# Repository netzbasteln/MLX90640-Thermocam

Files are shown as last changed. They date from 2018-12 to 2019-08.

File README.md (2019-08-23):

# MLX90640-Thermocam

We built a simple Thermal camera using the MLX90640 Sensor, an ESP32, a ILI9341 TFT, a 18650 battery in a 3D printed case.
It was featured in Netzbasteln #111: http://www.netzbasteln.de/#111 and still lacks interpolation.

Code Based on:
- Thermal Camera with image saving capability https://github.com/wilhelmzeuschner/arduino_thermal_camera_with_sd_and_img_processing
- SparkFun MLX90640 Examples https://github.com/sparkfun/SparkFun_MLX90640_Arduino_Example
- TFT_eSPI Library: https://github.com/Bodmer/, important: copy the included TFT_eSPI/Setup_User.h into the librar folder.

Hardware:
- ESP32 Devkit 4 (or any other ESP32): https://www.espressif.com/en/products/hardware/esp32-devkitc/overview
- MLX90640 Sensor Breakout Board: https://shop.pimoroni.com/products/mlx90640-thermal-camera-breakout (or the Sparkfun one)
- Display ILI9341 2.8": https://www.amazon.de/gp/product/B07DPMV34R/, https://www.pjrc.com/store/display_ili9341.html
- Charger TP4056: https://www.watterott.com/de/TP4056-Micro-USB-5V-1A-Lithium-Battery-Charger-with-Protection
- Battery 18650
- 3D Printed case:

ESP32 Pins (GND/VCC is obvious ;)
```
SENSOR_SDA 21
SENSOR_SCL 22
TFT_MISO 19
TFT_MOSI 23
TFT_SCLK 18
TFT_CS   15
TFT_DC    2
TFT_RST   4
```

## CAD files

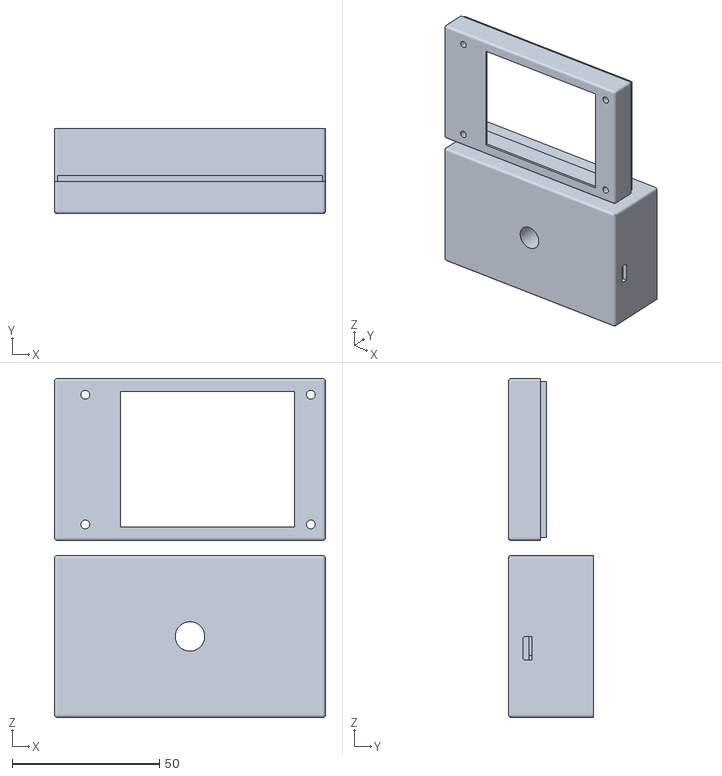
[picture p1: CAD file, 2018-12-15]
Wärmebildkamera-Gehäuse v49.stl
92.0 x 29.0 x 115.0

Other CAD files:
Wärmebildkamera-Gehäuse-v49.f3d

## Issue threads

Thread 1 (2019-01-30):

Which button to use?

weases, 2019-01-30:
I do not see a button to turn on/off the camera in the hardware list but it seems like there is a cut-out in the case. Can you point me in the direction which button was used in the project/would fit?

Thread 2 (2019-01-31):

'class TwoWire' has no member named 'transact'

digitalflower, 2019-01-31:
first of all thanks for the great project & podcast!

I installed the ESP32 core fork as described here: https://github.com/stickbreaker/arduino-esp32/blob/master/docs/arduino-ide/mac.md

But when compiling I get the following error:

```
sketch/MLX90640_I2C_Driver.cpp: In function 'int MLX90640_I2CRead(uint8_t, unsigned int, unsigned int, uint16_t*)':
MLX90640_I2C_Driver.cpp:60:20: error: 'class TwoWire' has no member named 'transact'
     int err = Wire.transact(_transact_buffer, numberOfBytesToRead);
                    ^
Multiple libraries were found for "SD.h"
 Used: /Users/user/Documents/Arduino/hardware/espressif/esp32/libraries/SD
 Not used: /Applications/Arduino.app/Contents/Java/libraries/SD
exit status 1
'class TwoWire' has no member named 'transact'
```
Arduino: 1.8.8 (Mac OS X), Board: "ESP32 Dev Module, Disabled, Default, 240MHz (WiFi/BT), QIO, 80MHz, 4MB (32Mb), 921600, None"

It seems the correct library is used. Any Ideas ? Thanks!

Closed 2019-02-01.

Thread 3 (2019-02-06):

display is just black

torst3n, 2019-02-06:
really like the thermocam project!
I am trying to build it with the exact same hardware components linked in the readme. My problem is that i can't get the display working it is just black. I connected the pins like that:

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

What did I do wrong ?
If I can get it working I would be happy to create a pull request (with the corrected wiring) to add the schematic to the readme.

Thanks for your help!

hpd96, 2019-02-26:
Hi, würde noch LED mit 3,3 V verbinden :-) Dein Plan scheint richtig zu sein . vg

torst3n, 2019-02-26:
> Hi, würde noch LED mit 3,3 V verbinden :-) Dein Plan scheint richtig zu sein . vg

Thanks for your help @hpd96 !! Now I have a white display.
I got a graphicstest running from the examples so the display is not the problem. When I debug with println I can see that the min / max temperatures are set and no other errors occur.
Any Ideas ?

hpd96, 2019-02-27:
Hi, use the user_setup.h oft this netzbasteln repo. Wunderbar vorkonfiguriert :-)
Overwrite the user_setup.h of TFT library !

My thermoCam working since yesterday ...

Great nova project !!

torst3n, 2019-02-28:
Mine is now also working! Thanks.

I totally missed that the user_setup.h of TFT_eSPI Library must be overwritten.

Closed 2019-02-28.

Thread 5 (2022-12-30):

The image is mirror'ed

classic-audio, 2022-12-30:
How can the image be mirror'ed?
I have build the IR camera and want to use it for fault findings in electronics (PCB).
But it is a big problem to use a mirror'ed image.

Help please

LBuydens, 2023-01-02:
I suppose you have the temperature values already in an array in the memory.  Try rearranging the columns of that array to mirror the image.

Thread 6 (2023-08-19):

Problems when runs on ESP32 S3 with OPI PSRAM

13286376917, 2023-08-19:
I testing this code with my ESP32 S3 with OPI PSRAM and some problem arise -- it reboots over and over again.And I find out that when I turn on the option of the OPI PSRAM,ESP32 S3 will reboot after building without any mistakes.

I just create a fork to solve this problem.

Closed 2024-03-23.

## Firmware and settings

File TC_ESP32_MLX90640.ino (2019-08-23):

/**
 * Based on: 
 * - https://github.com/wilhelmzeuschner/arduino_thermal_camera_with_sd_and_img_processing.
 * - https://github.com/sparkfun/SparkFun_MLX90640_Arduino_Example
 * 
 * Hardware:
 * - ESP32: https://www.espressif.com/en/products/hardware/esp32-devkitc/overview
 * - Sensor: https://shop.pimoroni.com/products/mlx90640-thermal-camera-breakout
 * - Display: https://www.amazon.de/gp/product/B07DPMV34R/, https://www.pjrc.com/store/display_ili9341.html
 */


#include <TFT_eSPI.h>
#include <SD.h>
#include <SPI.h>
#include <Wire.h>

#include "MLX90640_API.h"
#include "MLX90640_I2C_Driver.h"

#define EMMISIVITY 0.95
#define INTERPOLATE false

#define C_BLUE Display.color565(0,0,255)
#define C_RED Display.color565(255,0,0)
#define C_GREEN Display.color565(0,255,0)
#define C_WHITE Display.color565(255,255,255)
#define C_BLACK Display.color565(0,0,0)
#define C_LTGREY Display.color565(200,200,200)
#define C_DKGREY Display.color565(80,80,80)
#define C_GREY Display.color565(127,127,127)

#define min(a,b) ((a)<(b)?(a):(b))
#define max(a,b) ((a)>(b)?(a):(b))

const byte MLX90640_address = 0x33; //Default 7-bit unshifted address of the MLX90640
#define TA_SHIFT 8 //Default shift for MLX90640 in open air
paramsMLX90640 mlx90640;


TFT_eSPI Display = TFT_eSPI();


// Added for measure Temp
boolean measure = true;
float centerTemp;
unsigned long tempTime = millis();
unsigned long tempTime2 = 0;

// start with some initial colors
float minTemp = 20.0;
float maxTemp = 40.0;


// variables for interpolated colors
byte red, green, blue;

// variables for row/column interpolation
float intPoint, val, a, b, c, d, ii;
int x, y, i, j;


// array for the 32 x 24 measured tempValues
static float tempValues[32*24];

// Output size
#define O_WIDTH 224
#define O_HEIGHT 168
#define O_RATIO O_WIDTH/32

float **interpolated = NULL;
uint16_t *imageData = NULL;

void setup() {
  Serial.begin(115200);
  Serial.println("Hello.");

  // Connect thermal sensor.
  Wire.begin();
  Wire.setClock(400000); // Increase I2C clock speed to 400kHz
  Wire.beginTransmission((uint8_t)MLX90640_address);
  if (Wire.endTransmission() != 0) {
    Serial.println("MLX90640 not detected at default I2C address. Please check wiring.");
  }
  else {
    Serial.println("MLX90640 online!");
  }
  // Get device parameters - We only have to do this once
  int status;
  uint16_t eeMLX90640[832];
  status = MLX90640_DumpEE(MLX90640_address, eeMLX90640);
  if (status != 0) Serial.println("Failed to load system parameters");
  status = MLX90640_ExtractParameters(eeMLX90640, &mlx90640);
  if (status != 0) Serial.println("Parameter extraction failed");
  // Set refresh rate
  MLX90640_SetRefreshRate(MLX90640_address, 0x05); // Set rate to 8Hz effective - Works at 800kHz
  // Once EEPROM has been read at 400kHz we can increase
  Wire.setClock(800000);

  // Set up Display.
  pinMode(TFT_DC, OUTPUT);
  SPI.begin();
  SPI.setFrequency(80000000L);
  Display.begin();
  //Display.setRotation(3);
  Display.fillScreen(C_BLACK);


  // Prepare interpolated array
  interpolated = (float **)malloc(O_HEIGHT * sizeof(float *));
  for (int i=0; i<O_HEIGHT; i++) {
    interpolated[i] = (float *)malloc(O_WIDTH * sizeof(float));
  }

  // Prepare imageData array
  imageData = (uint16_t *)malloc(O_WIDTH * O_HEIGHT * sizeof(uint16_t));

  // get the cutoff points for the color interpolation routines
  // note this function called when the temp scale is changed
  setAbcd();
  drawLegend();
}


void loop() {
  tempTime = millis();
  
  readTempValues();
  setTempScale();
  drawPicture();
  drawMeasurement();
}


// Read pixel data from MLX90640.
void readTempValues() {
  for (byte x = 0 ; x < 2 ; x++) // Read both subpages
  {
    uint16_t mlx90640Frame[834];
    int status = MLX90640_GetFrameData(MLX90640_address, mlx90640Frame);
    if (status < 0)
    {
      Serial.print("GetFrame Error: ");
      Serial.println(status);
    }

    float vdd = MLX90640_GetVdd(mlx90640Frame, &mlx90640);
    float Ta = MLX90640_GetTa(mlx90640Frame, &mlx90640);

    float tr = Ta - TA_SHIFT; //Reflected temperature based on the sensor ambient temperature

    MLX90640_CalculateTo(mlx90640Frame, &mlx90640, EMMISIVITY, tr, tempValues);
  }
}


int row;
float temp, temp2;

void interpolate() {
  for (row=0; row<24; row++) {
    for (x=0; x<O_WIDTH; x++) {
      temp  = tempValues[(31 - (x/7)) + (row*32) + 1];
      temp2 = tempValues[(31 - (x/7)) + (row*32)];
      interpolated[row*7][x] = lerp(temp, temp2, x%7/7.0);
    }
  }
  for (x=0; x<O_WIDTH; x++) {
    for (y=0; y<O_HEIGHT; y++) {
      temp  = interpolated[y-y%7][x];
      temp2 = interpolated[min((y-y%7)+7, O_HEIGHT-7)][x];
      interpolated[y][x] = lerp(temp, temp2, 1);//y%7/7.0);
    }
  }
}


// Linear interpolation
float lerp(float v0, float v1, float t) {
  return v0 + t * (v1 - v0);
}


void drawPicture() {
  if (INTERPOLATE) {
    interpolate();
    for (y=0; y<O_HEIGHT; y++) {
      for (x=0; x<O_WIDTH; x++) {
        imageData[(y*O_WIDTH) + x] = getColor(interpolated[y][x]);
      }
    }
    Display.pushImage(8, 8, O_WIDTH, O_HEIGHT, imageData);
  }
  else {
    for (y=0; y<24; y++) {
      for (x=0; x<32; x++) {
        Display.fillRect(8 + x*7, 8 + y*7, 7, 7, getColor(tempValues[(31-x) + (y*32)]));
      }
    }
  }
}



// Get color for temp value.
uint16_t getColor(float val) {
  /*
    pass in value and figure out R G B
    several published ways to do this I basically graphed R G B and developed simple linear equations
    again a 5-6-5 color display will not need accurate temp to R G B color calculation

    equations based on
    http://web-tech.ga-usa.com/2012/05/creating-a-custom-hot-to-cold-temperature-color-gradient-for-use-with-rrdtool/index.html

  */

  red = constrain(255.0 / (c - b) * val - ((b * 255.0) / (c - b)), 0, 255);

  if ((val > minTemp) & (val < a)) {
    green = constrain(255.0 / (a - minTemp) * val - (255.0 * minTemp) / (a - minTemp), 0, 255);
  }
  else if ((val >= a) & (val <= c)) {
    green = 255;
  }
  else if (val > c) {
    green = constrain(255.0 / (c - d) * val - (d * 255.0) / (c - d), 0, 255);
  }
  else if ((val > d) | (val < a)) {
    green = 0;
  }

  if (val <= b) {
    blue = constrain(255.0 / (a - b) * val - (255.0 * b) / (a - b), 0, 255);
  }
  else if ((val > b) & (val <= d)) {
    blue = 0;
  }
  else if (val > d) {
    blue = constrain(240.0 / (maxTemp - d) * val - (d * 240.0) / (maxTemp - d), 0, 240);
  }

  // use the displays color mapping function to get 5-6-5 color palet (R=5 bits, G=6 bits, B-5 bits)
  return Display.color565(red, green, blue);
}


void setTempScale() {
  minTemp = 255;
  maxTemp = 0;

  for (i = 0; i < 768; i++) {
    minTemp = min(minTemp, tempValues[i]);
    maxTemp = max(maxTemp, tempValues[i]);
  }

  setAbcd();
  drawLegend();
}


// Function to get the cutoff points in the temp vs RGB graph.
void setAbcd() {
  a = minTemp + (maxTemp - minTemp) * 0.2121;
  b = minTemp + (maxTemp - minTemp) * 0.3182;
  c = minTemp + (maxTemp - minTemp) * 0.4242;
  d = minTemp + (maxTemp - minTemp) * 0.8182;
}


// Draw a legend.
void drawLegend() {
  float inc = (maxTemp - minTemp) / 224.0;
  j = 0;
  for (ii = minTemp; ii < maxTemp; ii += inc) {
    Display.drawFastVLine(8+ + j++, 292, 20, getColor(ii));
  }

  Display.setTextFont(2);
  Display.setTextSize(1);
  Display.setCursor(8, 272);
  Display.setTextColor(TFT_WHITE, TFT_BLACK);
  Display.print(String(minTemp).substring(0, 5));

  Display.setCursor(192, 272);
  Display.setTextColor(TFT_WHITE, TFT_BLACK);
  Display.print(String(maxTemp).substring(0, 5));

  Display.setTextFont(NULL);
}


// Draw a circle + measured value.
void drawMeasurement() {

  // Mark center measurement
  Display.drawCircle(120, 8+84, 3, TFT_WHITE);

  // Measure and print center temperature
  centerTemp = (tempValues[383 - 16] + tempValues[383 - 15] + tempValues[384 + 15] + tempValues[384 + 16]) / 4;
  Display.setCursor(86, 214);
  Display.setTextColor(TFT_WHITE, TFT_BLACK);
  Display.setTextFont(2);
  Display.setTextSize(2);
  Display.print(String(centerTemp).substring(0, 5) + " °C");
}

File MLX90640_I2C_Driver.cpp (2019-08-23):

/**
   @copyright (C) 2017 Melexis N.V.
   Licensed under the Apache License, Version 2.0 (the "License");
   you may not use this file except in compliance with the License.
   You may obtain a copy of the License at
       http://www.apache.org/licenses/LICENSE-2.0
   Unless required by applicable law or agreed to in writing, software
   distributed under the License is distributed on an "AS IS" BASIS,
   WITHOUT WARRANTIES OR CONDITIONS OF ANY KIND, either express or implied.
   See the License for the specific language governing permissions and
   limitations under the License.
*/

#include<Arduino.h>

#include <Wire.h>

#include "MLX90640_I2C_Driver.h"

void MLX90640_I2CInit()
{

}

//Read a number of words from startAddress. Store into Data array.
//Returns 0 if successful, -1 if error
int MLX90640_I2CRead(uint8_t _deviceAddress, unsigned int startAddress, unsigned int nWordsRead, uint16_t *data)
{

  //Caller passes number of 'unsigned ints to read', increase this to 'bytes to read'
  uint16_t bytesRemaining = nWordsRead * 2;

  //It doesn't look like sequential read works. Do we need to re-issue the address command each time?

  uint16_t dataSpot = 0; //Start at beginning of array

  //Setup a series of chunked I2C_BUFFER_LENGTH byte reads
  while (bytesRemaining > 0)
  {
    Wire.beginTransmission(_deviceAddress);
    Wire.write(startAddress >> 8); //MSB
    Wire.write(startAddress & 0xFF); //LSB
    if (Wire.endTransmission(false) != 0) //Do not release bus
    {
      Serial.println("No ack read");
      return (0); //Sensor did not ACK
    }

    uint16_t numberOfBytesToRead = bytesRemaining;
    if (numberOfBytesToRead > I2C_BUFFER_LENGTH) numberOfBytesToRead = I2C_BUFFER_LENGTH;

    Wire.requestFrom((uint8_t)_deviceAddress, numberOfBytesToRead);
    if (Wire.available())
    {
      for (uint16_t x = 0 ; x < numberOfBytesToRead / 2; x++)
      {
        //Store data into array
        data[dataSpot] = Wire.read() << 8; //MSB
        data[dataSpot] |= Wire.read(); //LSB

        dataSpot++;
      }
    }

    bytesRemaining -= numberOfBytesToRead;

    startAddress += numberOfBytesToRead / 2;
  }

  return (0); //Success
}

//Set I2C Freq, in kHz
//MLX90640_I2CFreqSet(1000) sets frequency to 1MHz
void MLX90640_I2CFreqSet(int freq)
{
  //i2c.frequency(1000 * freq);
  Wire.setClock((long)1000 * freq);
}

//Write two bytes to a two byte address
int MLX90640_I2CWrite(uint8_t _deviceAddress, unsigned int writeAddress, uint16_t data)
{
  Wire.beginTransmission((uint8_t)_deviceAddress);
  Wire.write(writeAddress >> 8); //MSB
  Wire.write(writeAddress & 0xFF); //LSB
  Wire.write(data >> 8); //MSB
  Wire.write(data & 0xFF); //LSB
  if (Wire.endTransmission() != 0)
  {
    //Sensor did not ACK
    Serial.println("Error: Sensor did not ack");
    return (-1);
  }

  uint16_t dataCheck;
  MLX90640_I2CRead(_deviceAddress, writeAddress, 1, &dataCheck);
  if (dataCheck != data)
  {
    //Serial.println("The write request didn't stick");
    return -2;
  }

  return (0); //Success
}

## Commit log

2018-12-15 Initial Upload
    [Wärmebildkamera-Gehäuse v49.stl, Wärmebildkamera-Gehäuse-v49.f3d]
2019-08-23 ESP32 library fork no longer needed, move User_setup.h
    [MLX90640_I2C_Driver.cpp, User_Setup.h]
2019-08-23 Re-add Arduino.h import
